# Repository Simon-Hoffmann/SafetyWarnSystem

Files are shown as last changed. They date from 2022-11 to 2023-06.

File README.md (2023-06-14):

# SafetyWarnSystem

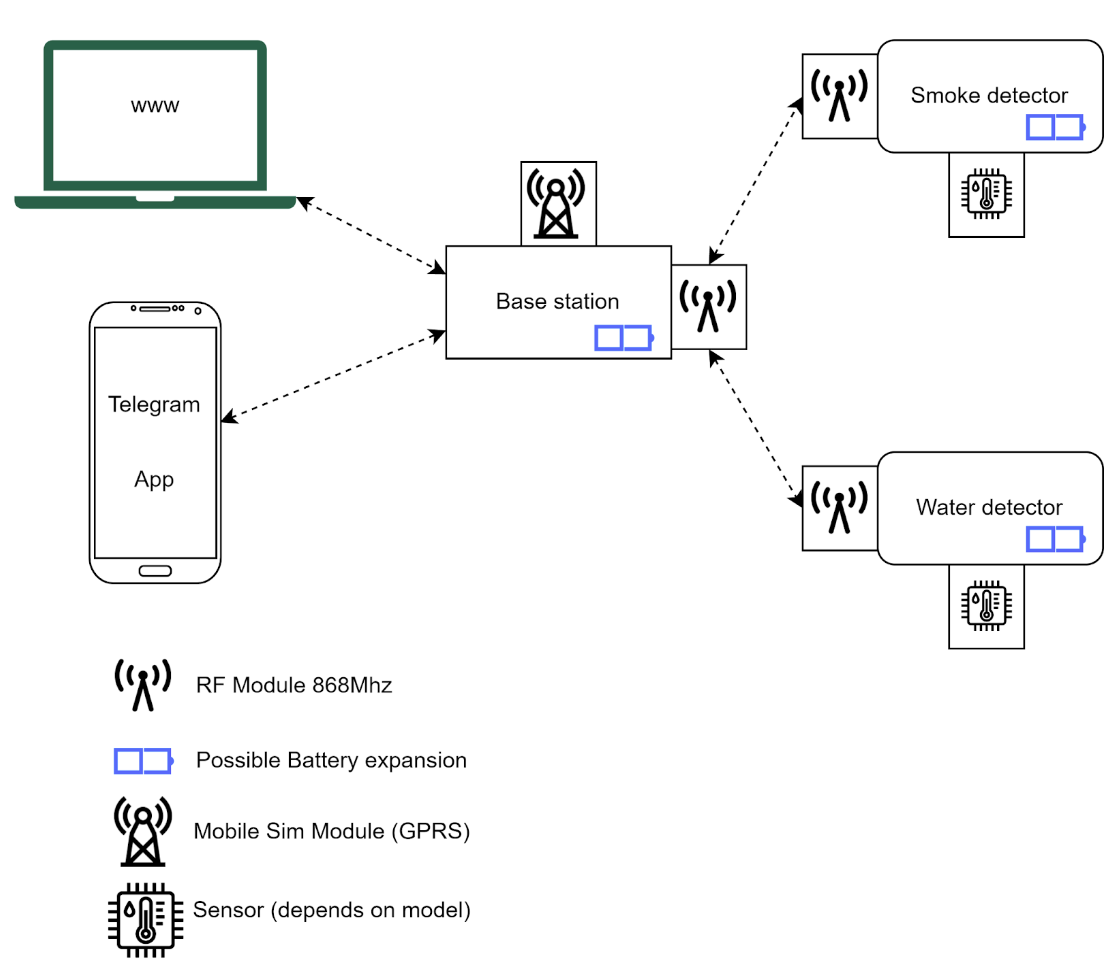
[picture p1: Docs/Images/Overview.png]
System


Introducing our Safety Warn System, a comprehensive home security solution designed to keep you and your loved ones safe at all times.

At the heart of the Safety Warn System is the Base Station, serving as the centralized hub for all sensor communication. This device is easily installed in your home, acting as the control center for your security network. Equipped with radio frequency technology, the Base Station seamlessly interacts with the array of sensors connected to it, ensuring real-time monitoring and instant notifications.

The Safety Warn System includes four essential sensors, each playing a crucial role in safeguarding your home. The Smoke and Gas Alarm sensor ensures early detection of smoke and potentially harmful gases, promptly alerting you to potential fire hazards or gas leaks. The Water Detector sensor is designed to identify any water leaks or floods, enabling you to take immediate action and prevent costly water damage. Lastly, the Door Open Detector sensor provides reliable surveillance, instantly notifying you whenever a door or window is opened, securing your home against intrusions.

When any of the sensors detect an issue, they immediately communicate with the Base Station, relaying the crucial information. The Base Station acts as the liaison, promptly relaying notifications to you through a user-friendly website and a dedicated Telegram bot. This allows you to conveniently access the Base Station from anywhere, giving you complete control and situational awareness of your home security.

Through the intuitive website and Telegram bot, you can monitor the status of each sensor, view real-time alerts, and access historical data. Additionally, you have the ability to customize your notifications based on your preferences, ensuring that you receive the right information at the right time.

## Hardware

### Microcontroller

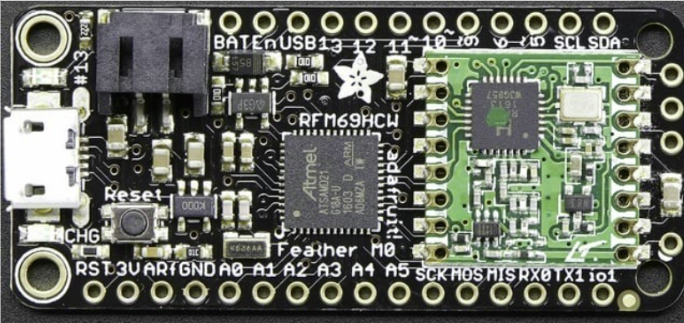
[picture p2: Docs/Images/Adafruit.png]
Controller


This adafruit board is a very useful microcontroller because of the following reasons:

- It has a built in RFM module
- It has a battery port for direct battery operation support
- Its form is very small, smaller than the 2 previous microcontrollers
- Adafruit works with the Arduino IDE and with this supports all Arduino libraries

Each microcontroller will have a button for resetting the sensor to factory settings. The following was chosen because it short circuits two connections on press, allowing the use of an interrupt to wake the sensor up during sleep. I did not compare other buttons, since there aren’t many criteria for the button, so any cheap button will do.

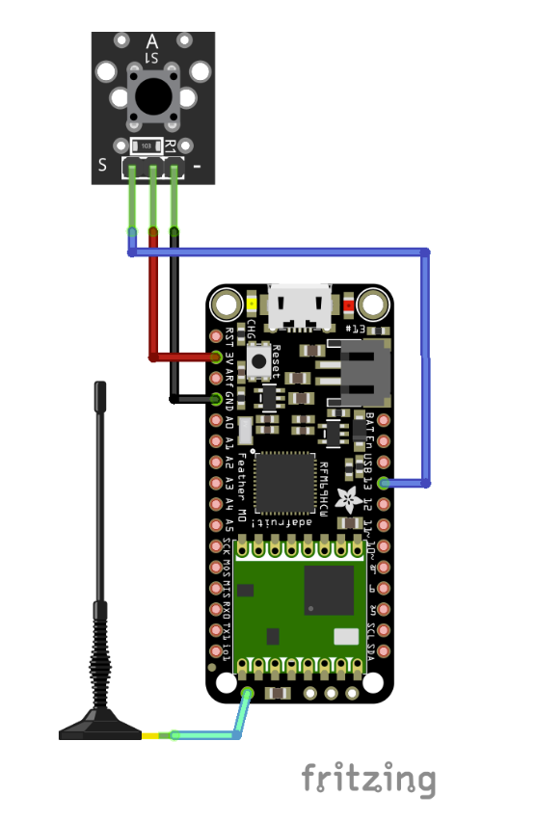
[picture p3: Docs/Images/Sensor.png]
Sensor


### Smoke Detector and Gas Detector

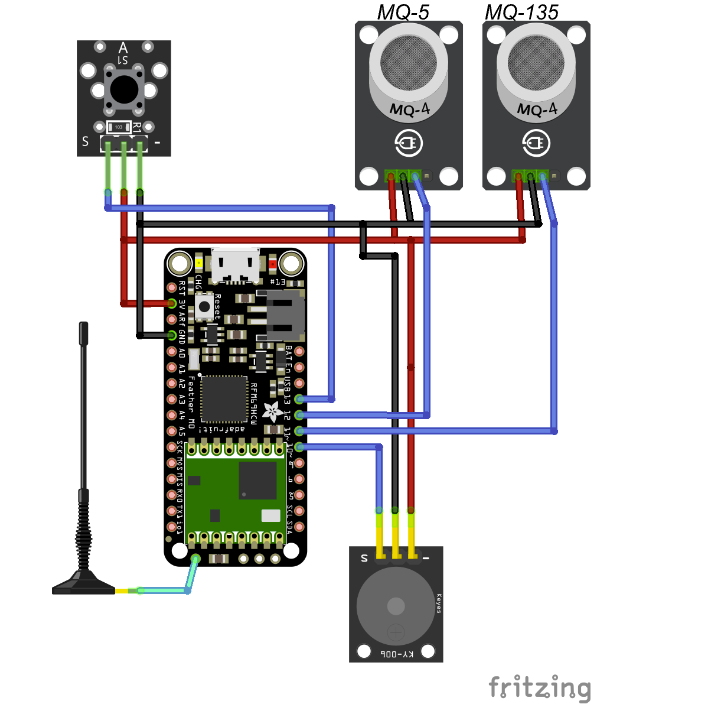
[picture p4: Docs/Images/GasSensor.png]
GasSensor


The smoke detector needs three different hardware components:
- MQ-135 Sensor has the capabilities of detecting: Benzene, alcohol, smoke in the air or to measure the air quality.
- MQ-5 Sensor has the capabilities for measuring the concentration of liquefied petroleum gases (LPG), carbon monoxide (CO), methane (CH4) and hydrogen (H2) in the air.
- A buzzer to indicate the detection of smoke or a dangerous gas with a loud beeping sound.

The smoke detector also needs to have a button with the functionality of turning off the buzzer alarm manually when it goes off. For this purpose, the button on the microcontroller of the sensor module will be used. 

### Water sensor

WaterSensor

## Door sensor

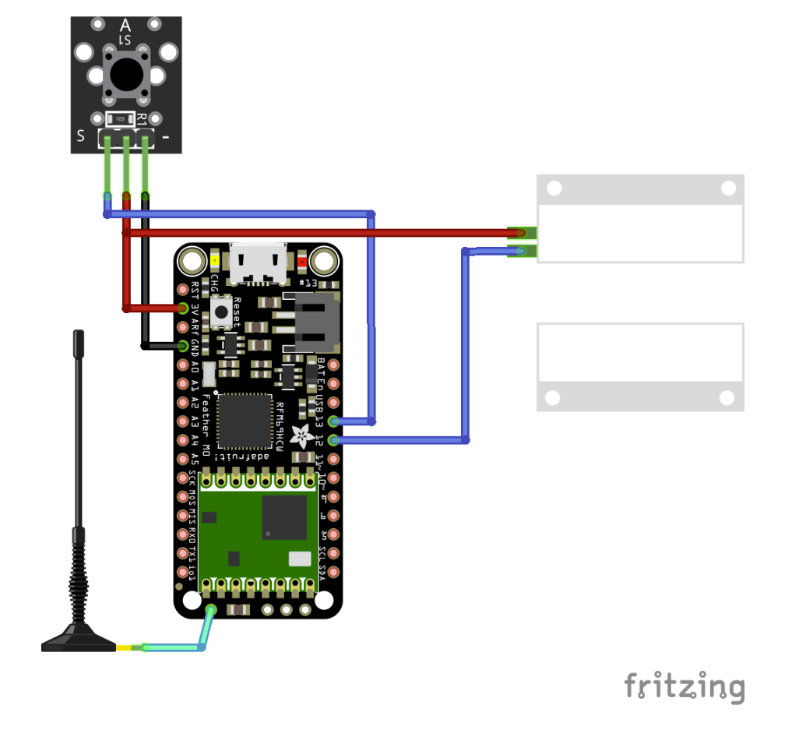
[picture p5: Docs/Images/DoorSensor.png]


## Communication

Before we could begin with the implementation of the sensors, we had to decide how the communication would be done between the sensors and the base station. We came up with the following solution.

### Packet Format

| idSensor | idBase | packetID | packetType | DataLength | Data |
| --- | --- | --- | --- | --- | --- |
| uint8_t | uint8_t | uint8_t | uint8_t | uint8_t | variable |

- idSensor    -       	unique id for sensor
- isBase      -       	unique id for Base Station
- packetID    -       	unique packet id for when a message is answered
- packetType 	-       	The type of data being sent
- DataLength 	-	        Indicates packet length
- Data        -       	Packet data

### Packet types

| Packettype | idSensor | idBase | packetID | packetType | Data |
| --- | --- | --- | --- | --- | --- |
| CONNECT | 0 | 0 | uint8_t | 1 | Sensor Type*  |
| CONNACK | 0 | 0 | uint8_t | 2 | ID for Sensor*|
| | | | | 3 | |
| ACK | uint8_t | uint8_t | uint8_t | 4 | - |
| SEND | uint8_t | uint8_t | uint8_t | 5 | See Send data |
| PING | uint8_t | uint8_t | uint8_t | 6 | - |
| DISCONNECT | uint8_t | uint8_t | uint8_t | 7 | - |

*uint8_t
Sensor Type: 
- 1 - Water sensor
- 2 - Smoke detector
- 3 - Door sensor

### Send data

Water Sensor

| Sensor type | Submerged (uint8_t)  |
| --- | --- |
| 1 | 0 or 1 |

Smoke Sensor

| Sensor type | Gas detection - time turned off (uint8_t) minutes  | Smoke sensor (uint16_t) ppm | Gas sensor (uint16_t) ppm |
| --- | --- | --- | --- |
| 2 | n | n | n |

Door Sensor

| Sensor type | Door state (uint8_t) |
| --- | --- |
| 3 | 0 open or 1 closed |

### Communication examples

#### Connection establishment new Connection

Sensor has no ID (Default: 0) meaning it needs one assigned

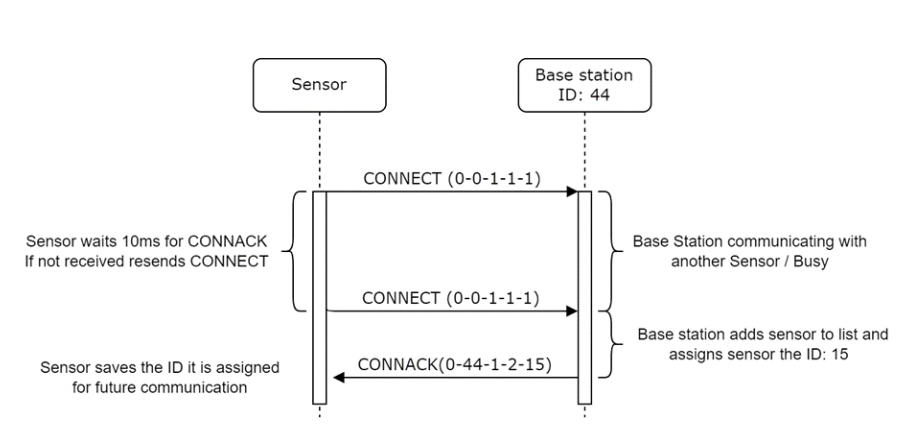
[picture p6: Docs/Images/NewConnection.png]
NewConnection


If the sensor doesn’t receive a CONNACK after 10 tries it sleeps for 1 min.

#### Connection establishment existing Connection

Sensor has ID: 15

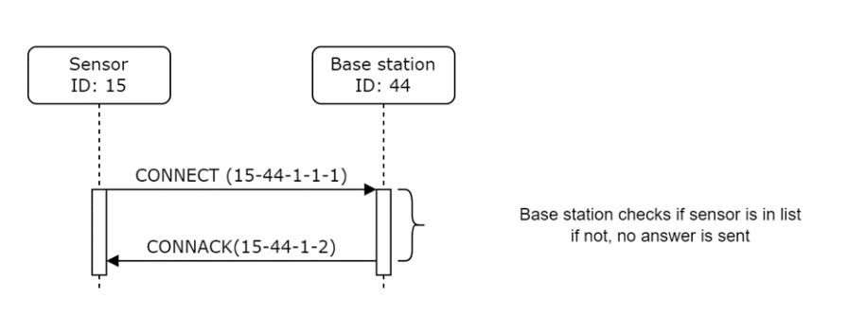
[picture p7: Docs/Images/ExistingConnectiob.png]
ExistingConnection


If the sensor doesn’t receive a CONNACK after 10 tries it sleeps for 1 min.

#### Disconnect

Disconnect can only be done upon receiving a PING Packet or SEND Packet, because the Sensor RF Module is not constantly active. The SEND happens every 10 minutes, allowing a relatively timely disconnect.
If the base does not get an ACK after 10 tries, it will retry disconnect after the next ping from the sensor.
To disconnect a sensor it should be deleted from the sensor_data.json

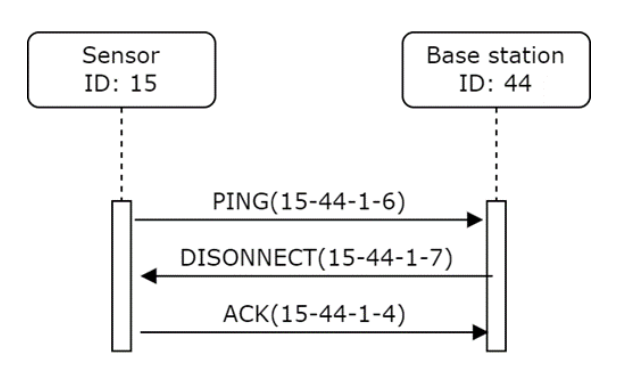
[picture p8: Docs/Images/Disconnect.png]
Disconnect


#### Ping

The sensor must send a PING Packet ever 1min to the Base station to indicate it is still active. If the base station does not receive a packet after 10min, it sets the sensor status to offline/error.
If the sensor does not get an ACK/DISCONNECT after 10 tries, it must retry connecting to the station.

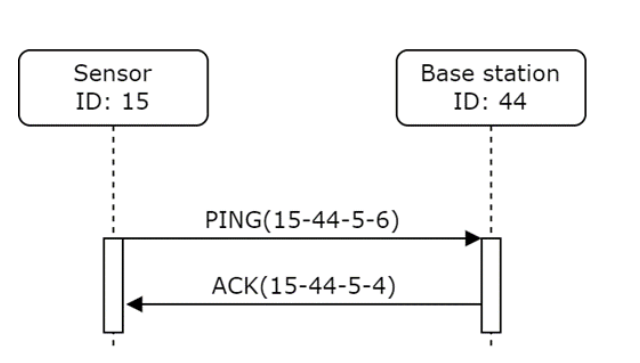
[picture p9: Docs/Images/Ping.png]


#### Sending Data

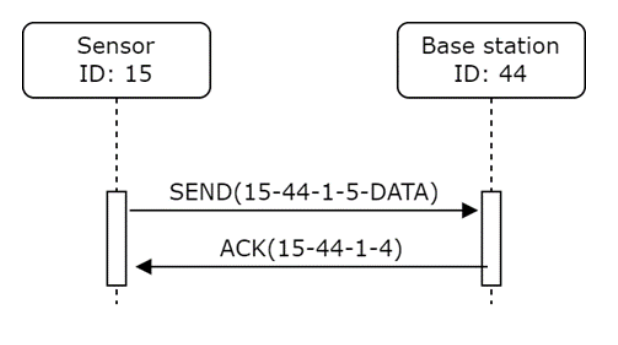
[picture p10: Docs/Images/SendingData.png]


Data is sent until an acknowledge is received (every 10ms up to 10 tries)
Base station sends ACK back to the sensor.
If the sensor does not get an ACK/DISCONNECT after 10 tries, it must retry connecting to the station.
Base station ignores duplicate messages.
If the base station does not receive a packet after 15min, it sets the sensor status to offline/error.

## Program flow chart

This flowchart is only for a rough overview and does not go into every specific detail. It is for a rough idea of how the sensors should operate.

### Program start

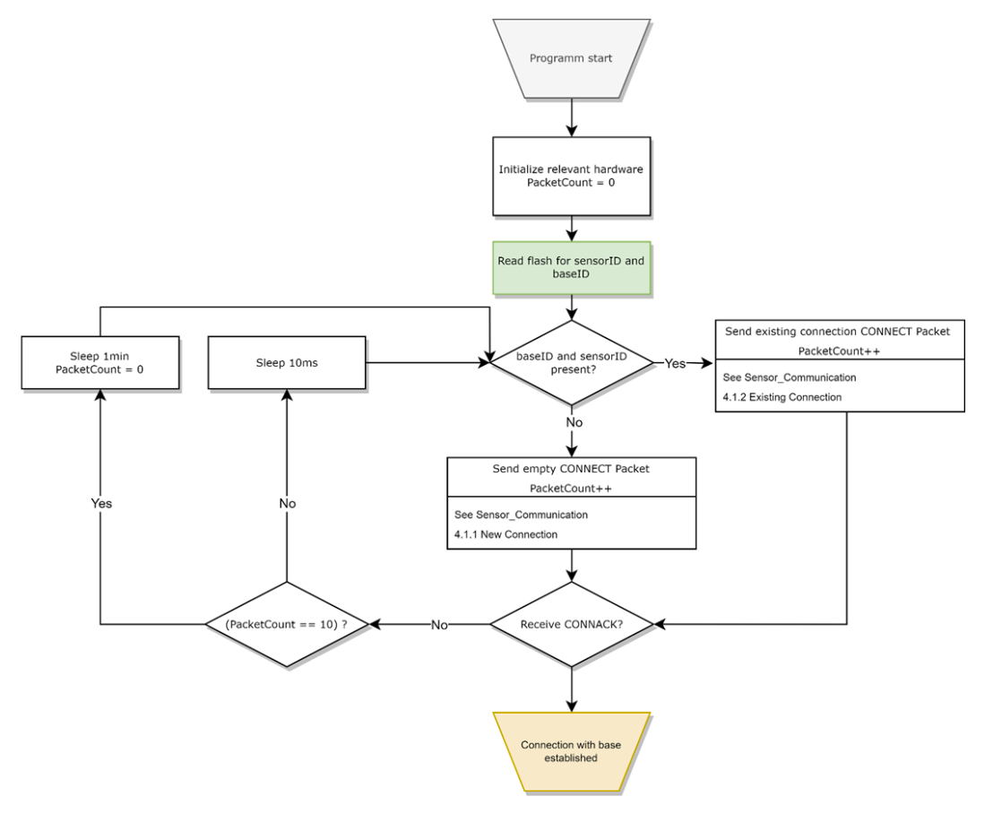
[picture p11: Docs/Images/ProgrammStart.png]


### Connected with base station

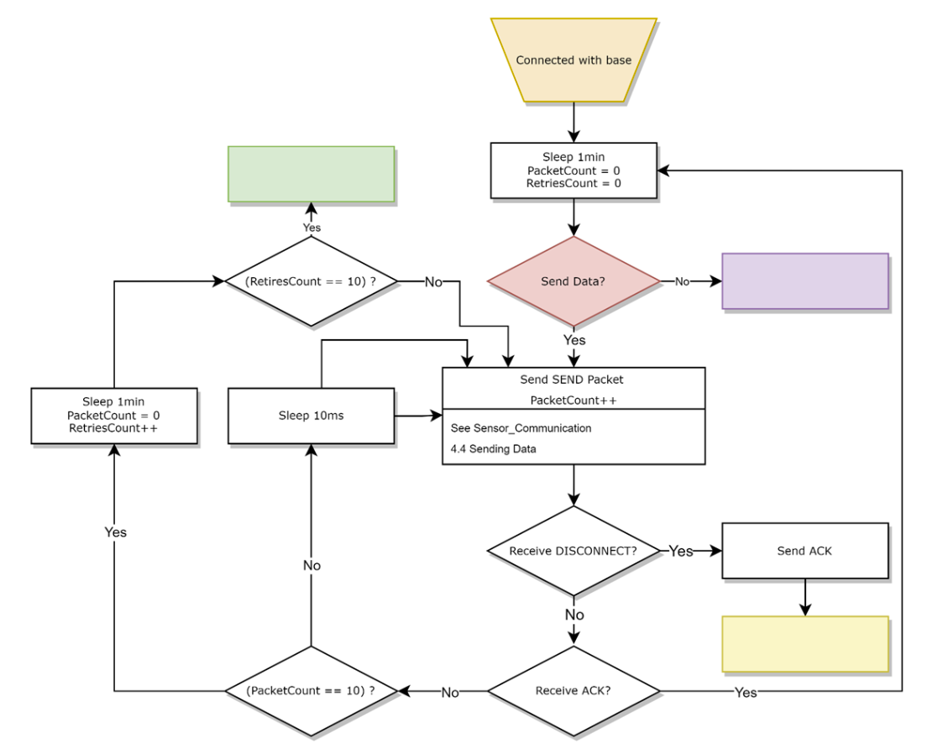
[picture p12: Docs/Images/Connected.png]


### Ping

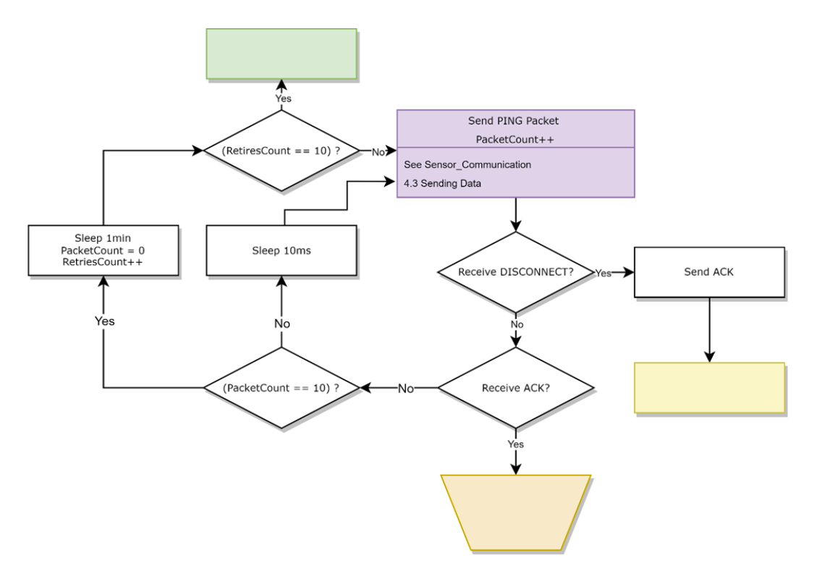
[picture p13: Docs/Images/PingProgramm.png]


### Sensor warning interrupt

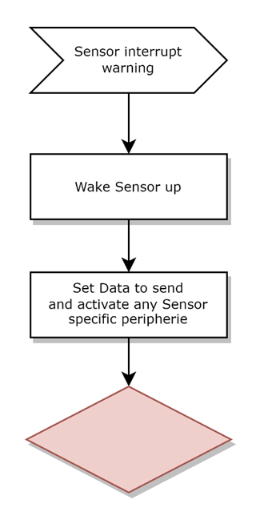
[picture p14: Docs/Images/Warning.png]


### Reset button main sensor

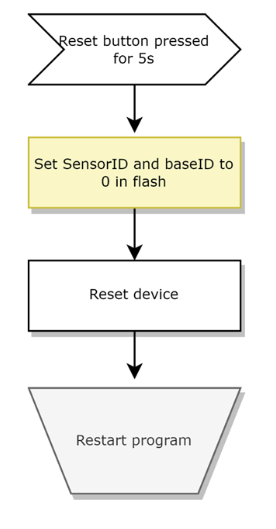
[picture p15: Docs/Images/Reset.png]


### Reset button smoke sensor

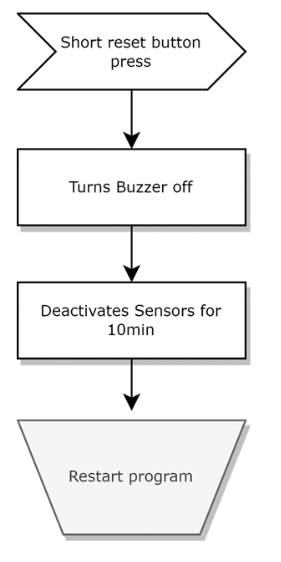
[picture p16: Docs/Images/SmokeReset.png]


### Reset button main sensor

Disconnect

## TODO

The base station and website are projects from other students in my course, which are currently not in this repository

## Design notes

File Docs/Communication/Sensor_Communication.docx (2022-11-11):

# Client-Server Communication Model

# Between sensor and base station

Author: Simon Hoffmann

Last edited: 09.11.2022

# 1. Packet format

idSensor | idBase | packetID | packetType | Data | End identifier
uint8_t | uint8_t | uint8_t | uint8_t | variable | ~

idSensor - unique id for sensor

isBase - unique id for Base Station

packetID - unique packet id for when a message is answered

packetType - The type of data being sent

Data - Packet data

End identifier - Indicates end of package

# 2. Packet types

Packettype | idSensor | idBase | packetID | packetType | Data
CONNECT | 0 | 0 | n | 1 | Sensor Type*
CONNACK | 0 | uint8_t | n | 2 | Id for Sensor+
| | | | 3
ACK | uint8_t | uint8_t | m | 4 | -
SEND | uint8_t | uint8_t | k | 5 | See Send Data
PING | uint8_t | uint8_t | i | 6 | -
DISCONNECT | uint8_t | uint8_t | g | 7 | -

+Id for Sensor (uint8_t)

*Sensor Type (uint8_t):

1 – Water sensor

2 – Smoke detector

3 –

# 3. Send Data

First part is uint8_t with type of sensor

## 3.1 Water Sensor

The Raspberry pi Pico have temperature sensors, the conversion must be done base station side.

Sensor type (uint8_t) | Humidity (uint16_t) | Submerged (uint8_t) | Temperature (uint16_t)
1 | n | 0 or 1 | n

## 3.2 Smoke Detector

Sensor type (uint8_t) | Smoke / CO2 detection | CO detection | Temperature (uint16_t)
2 | Not sure if can discern the difference | Not sure if can discern the difference | n

# 4. Communication examples

## 4.1 Connection establishment

### 4.1.1 New Connection

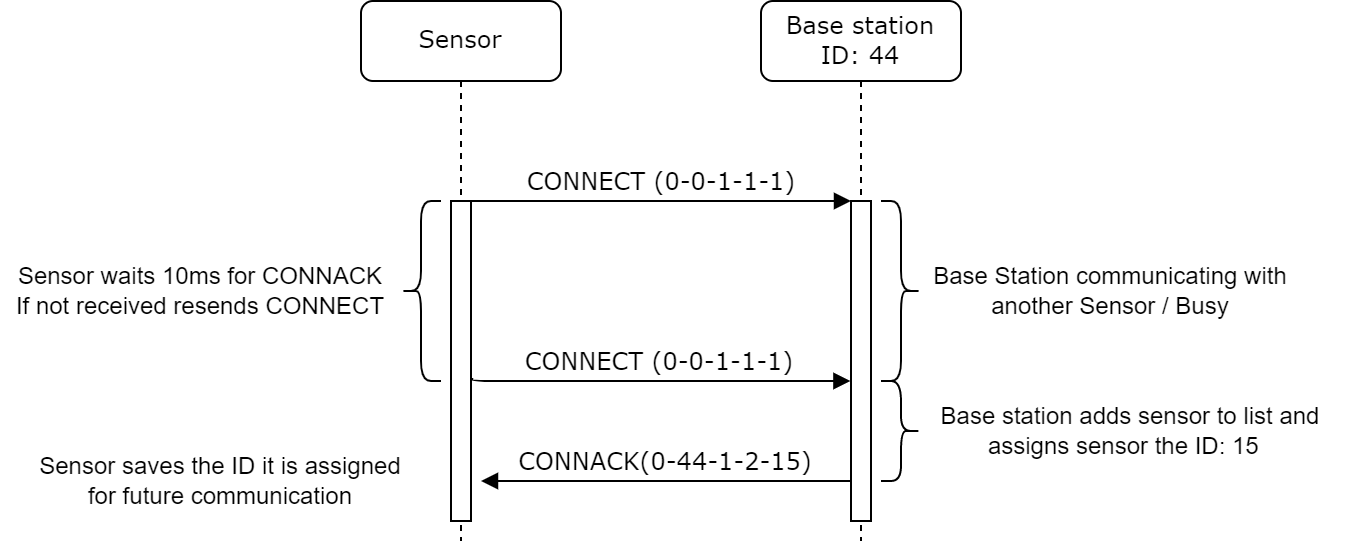
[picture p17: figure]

Sensor has no ID (Default: 0) meaning it needs one assigned

If sensor doesn’t receive a CONNACK after 10 tries it sleeps for 1min.

### 4.1.2 Existing Connection

Sensor has ID: 15

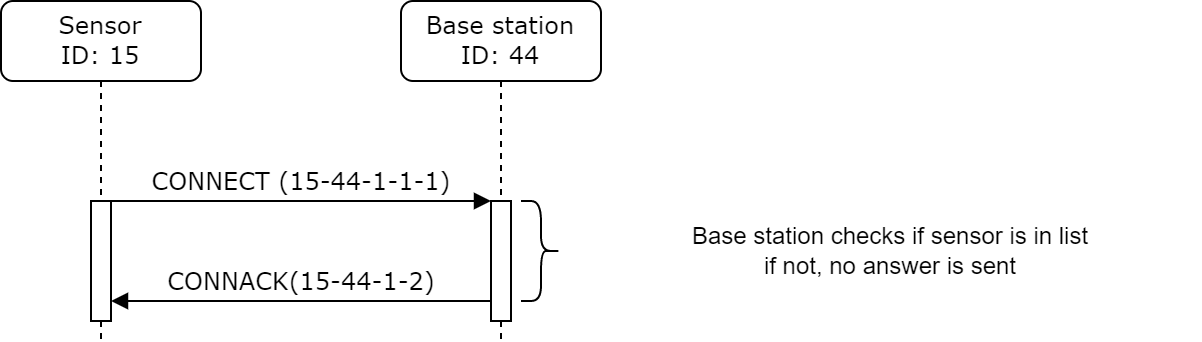
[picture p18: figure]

If sensor doesn’t receive a CONNACK after 10 tries it sleeps for 1min.

## 4.2 Disconnect

Disconnect can only be done upon receiving a PING Packet, because the Sensor RF Module is not constantly active. The Ping happens every minute, allowing a relatively timely disconnect.

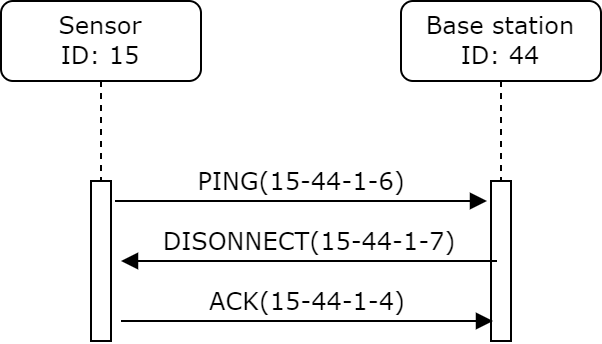
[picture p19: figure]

## 4.3 Connection available (PING)

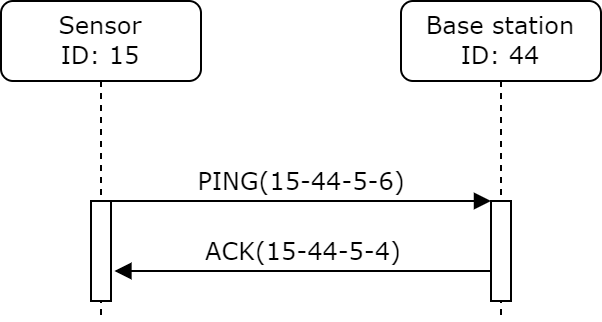
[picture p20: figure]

The sensor must send a PING Packet ever 1min to the Base station to indicate it is still active. If the base station does not receive a packet after 2min, it sets the sensor status to offline/error.

If the sensor does not get an ACK/DISCONNECT after 10 tries, it must retry connecting to the station.

This must only happen if nothing was sent in the 1min span.

## 4.4 Sending Data

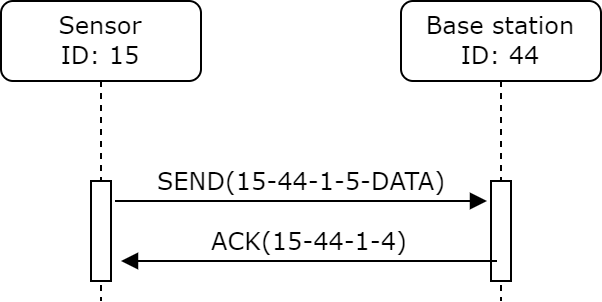
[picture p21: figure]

Data is sent until an acknowledge is received (every 10ms up to 10 tries)

Base station sends ACK back to sensor.

If the sensor does not get an ACK/DISCONNECT after 10 tries, it must retry connecting to the station.

Base station must ignore duplicate messages (with previous and current states maybe)

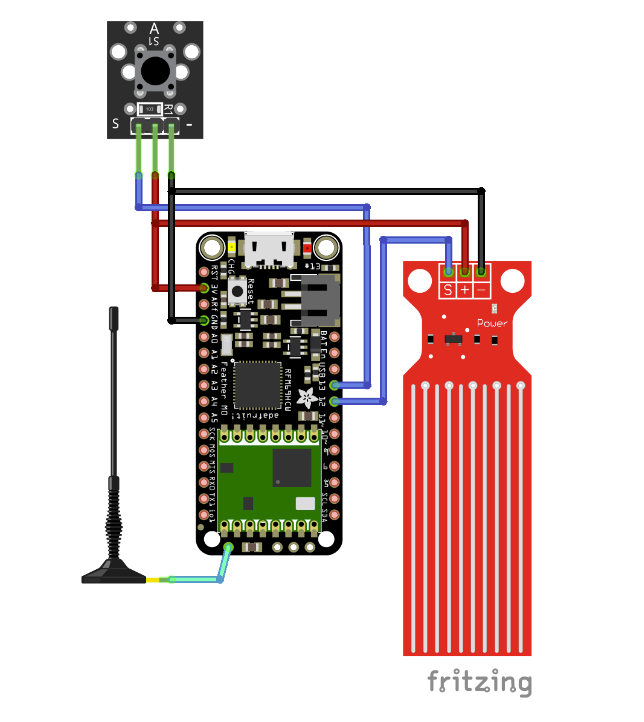
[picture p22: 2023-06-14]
Docs/Images/WaterSensor.png

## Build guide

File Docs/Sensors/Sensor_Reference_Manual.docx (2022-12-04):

Sensor Reference Manual

Author: Simon Hoffmann

Last edited: 3.12.2022

# 1. Program Flow-Chart

This flowchart is only for a rough overview and does not go into every specific detail.

## 1.1 Program start

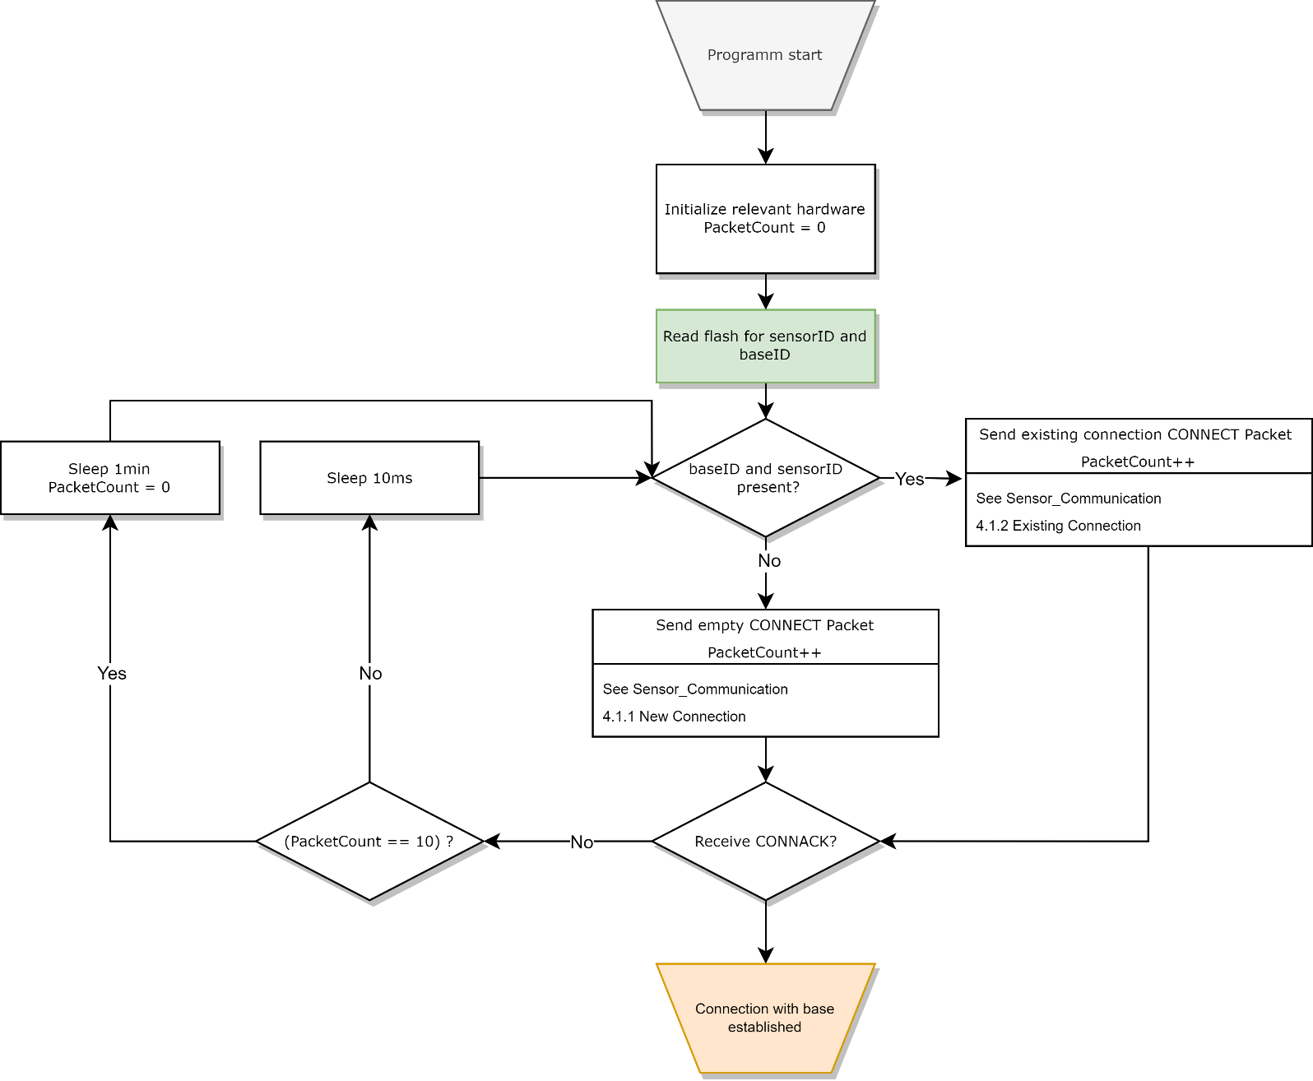
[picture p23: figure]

The program start initialises all hardware and tries to establish a connection with a base station.

See Connection with base established.

## 1.2 Connected with base station

The Sensor goes into sleep mode to save battery, when awoken it checks if it needs to send data, otherwise it sends a ping to let the base station know it is still active.

This is dependent on the sensor, some send constant information like temperature, others only if an event has occurred.

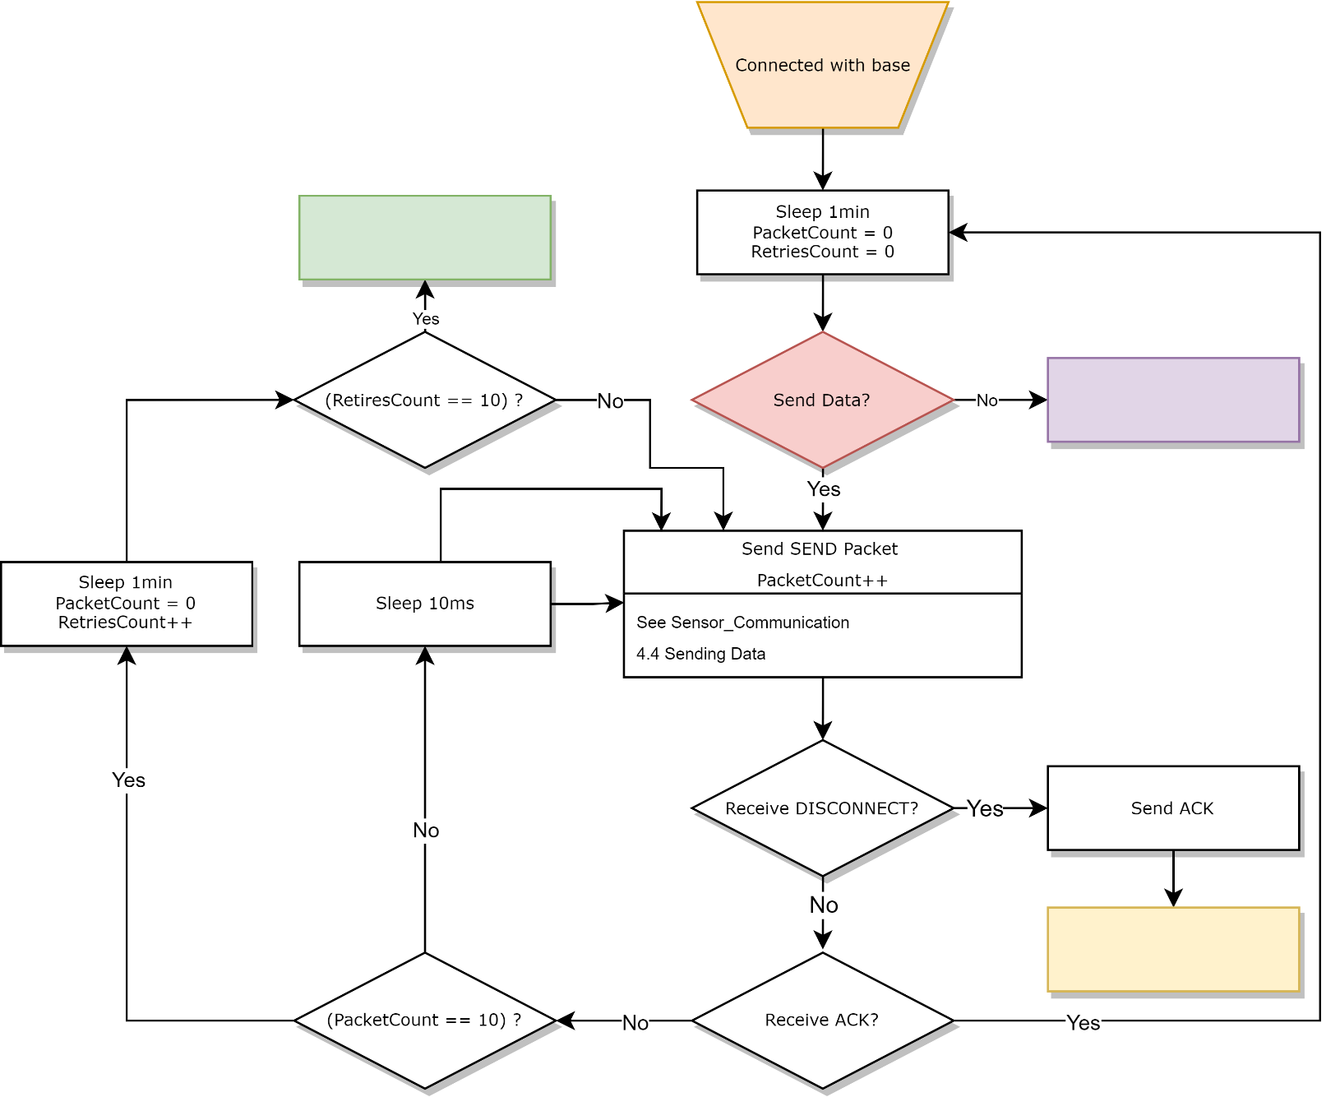
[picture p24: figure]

If an event has occurred that data precedes any other data trying to be sent.

See (RetriesCount == 10) ,No Data to send.

## 1.3 PING

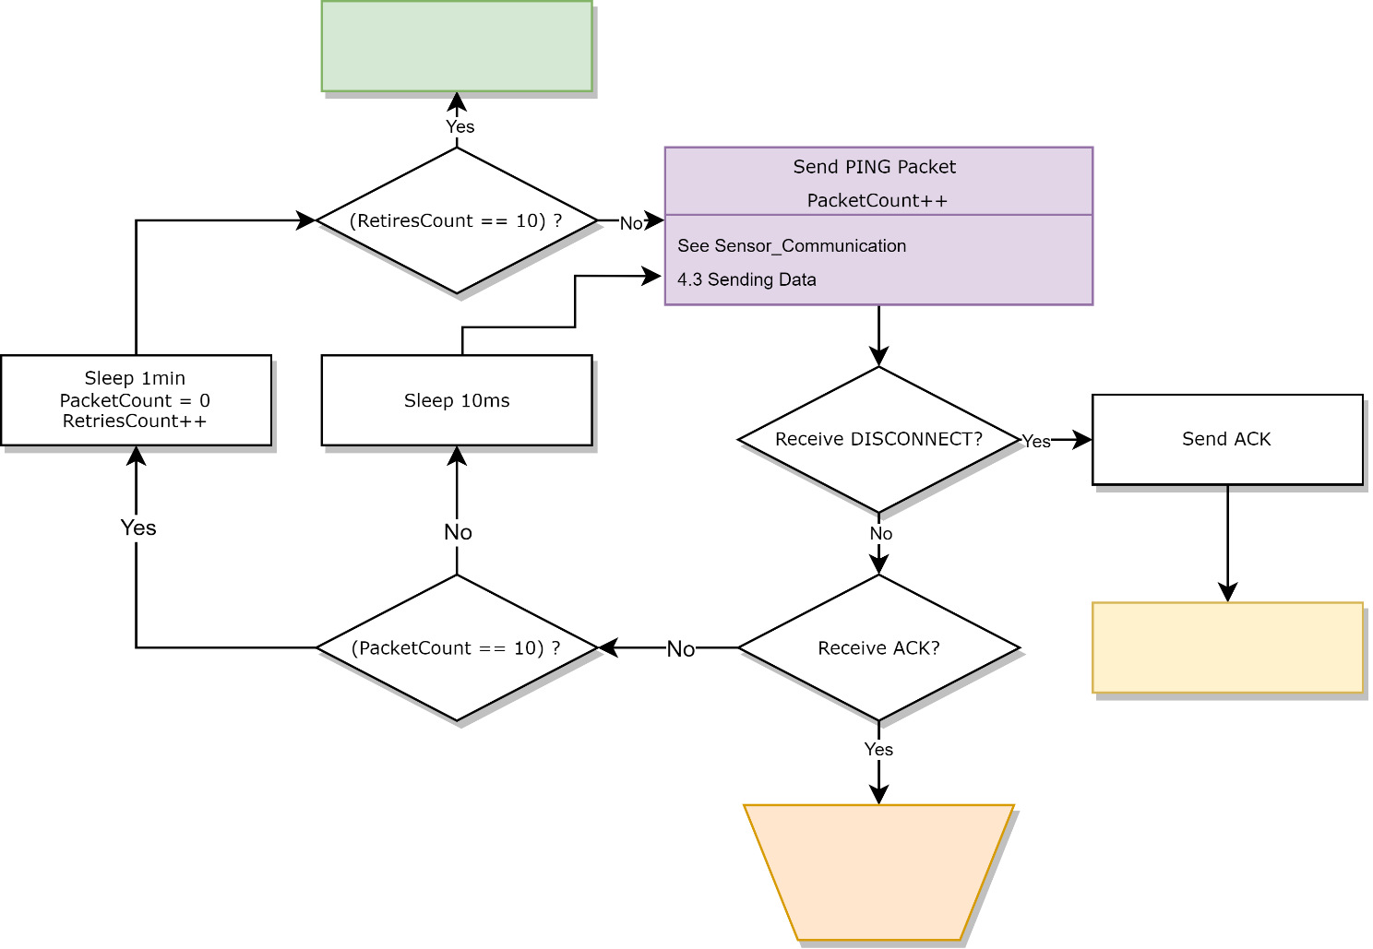
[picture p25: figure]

See (RetiresCount == 10), Send ACK, Received ACK.

## 1.4 Sensor warning interrupt

This is executed in an interrupt context, the exact implementation is Sensor dependent.

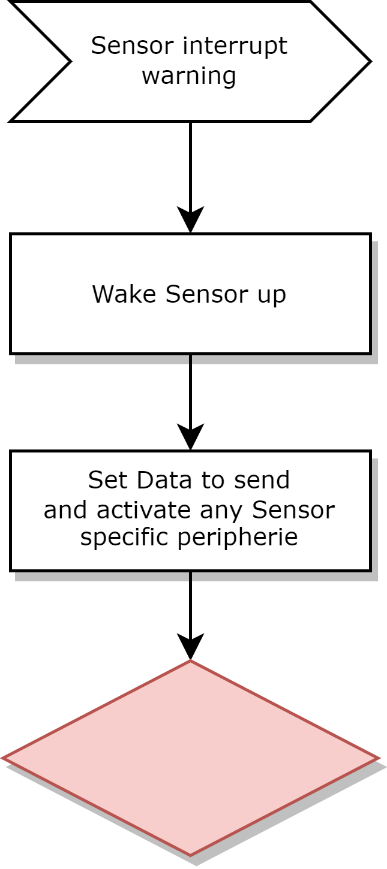
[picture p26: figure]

See Send Data.

## 1.5 Reset button held for 5s

This allows a user to manually reset the Sensor to connect it to a different base station.

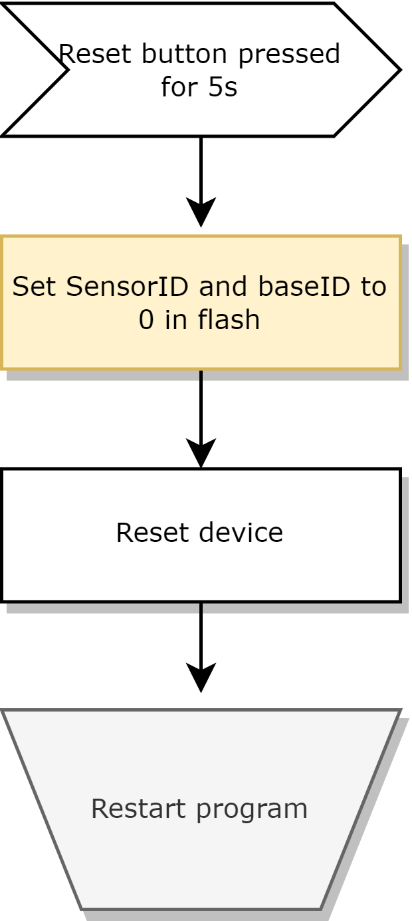
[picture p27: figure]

See Start Program.

## 1.6 Sensor Specific: Smoke detector – Reset button pressed shortly

This functionality is only on the Smoke detector sensor

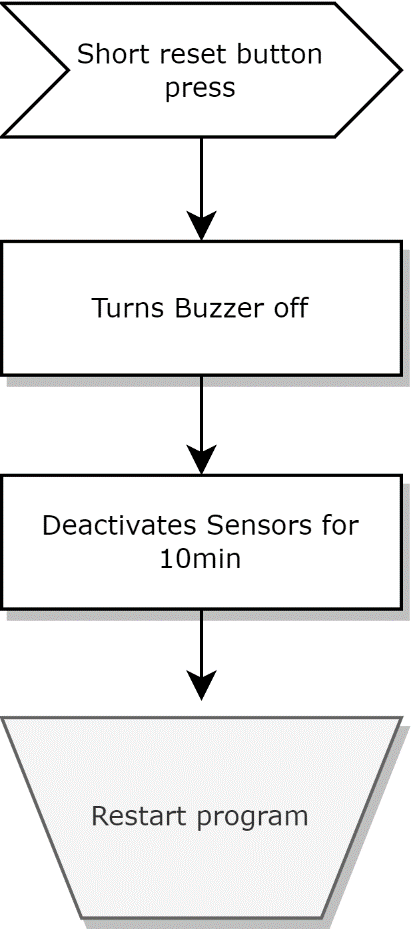
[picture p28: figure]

See Program start.

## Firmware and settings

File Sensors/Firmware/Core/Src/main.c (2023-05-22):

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
/* Includes ------------------------------------------------------------------*/
#include "main.h"
#include "rfm69w.h"
#include <string.h>

SPI_HandleTypeDef hspi2;

TIM_HandleTypeDef htim1;

void SystemClock_Config(void);
static void MX_GPIO_Init(void);
static void MX_SPI2_Init(void);
static void MX_TIM1_Init(void);
#define Send 0
#define Receive 1

/**
  * @brief  The application entry point.
  * @retval int
  */
int main(void)
{
  /* MCU Configuration--------------------------------------------------------*/

  /* Reset of all peripherals, Initializes the Flash interface and the Systick. */
  HAL_Init();

  /* Configure the system clock */
  SystemClock_Config();

  /* Initialize all configured peripherals */
  MX_GPIO_Init();
  MX_SPI2_Init();
  MX_TIM1_Init();
  /* USER CODE BEGIN 2 */
  	SWS_Packet packet;
    DataBuffer buffer;
    SmokeSensorData smokeData;
    packet.packetID = 0;
    packet.idBase = 1;
    packet.idSensor = 2;
    packet.packetID = packet.packetID + 1;
    packet.packetType = SEND;
//    smokeData.GasDetectionTimeout_Minutes = 10;
//    smokeData.GasSensor = 500;
//    smokeData.SmokeSensor = 1000;
//    smokeData.SensorType = 2;
//    smokeData.Temperature = 52;

#if Send
    memcpy(packet.data, &smokeData, 8);

    packet_serializeData(&packet, &buffer);
#endif

  /* USER CODE END 2 */

  /* Infinite loop */
  /* USER CODE BEGIN WHILE */
  bool RFM_active = false;
#if Send
  RFM_active = RFM69_initialize(RF69_868MHZ, 1, 0);

  while(!RFM_active){
	  RFM_active = RFM69_initialize(RF69_868MHZ, 1, 0);
	  HAL_Delay(1000);
  }
#endif
#if Receive
  RFM_active = RFM69_initialize(RF69_868MHZ, 2, 1);

  while(!RFM_active){
	  RFM_active = RFM69_initialize(RF69_868MHZ, 2, 1);
	  HAL_Delay(1000);
  }
#endif

#if Receive
  RFM69_setMode(RF69_MODE_RX);
#endif
  while (1)
  {
    /* USER CODE END WHILE */
	  if(RFM_active){
#if Send
		  RFM69_setMode(RF69_MODE_RX);
		  if(RFM69_canSend()){
			  RFM69_setMode(RF69_MODE_TX);
			  RFM69_send(RF69_BROADCAST_ADDR, buffer.data, buffer.size, false);
			  HAL_GPIO_WritePin(GPIOA, GPIO_PIN_5, 1);
		  }
		  RFM69_setMode(RF69_MODE_RX);
		  HAL_Delay(2500);
		  HAL_GPIO_WritePin(GPIOA, GPIO_PIN_5, GPIO_PIN_RESET);
		  HAL_Delay(2500);
#endif

#if Receive
		  if(RFM69_receive(buffer.data, buffer.size)){
			  packet_deserializeData(&packet, &buffer);
			  memcpy(&smokeData, packet.data, 8);
		  }
		  HAL_Delay(500);
#endif
	  }
    /* USER CODE BEGIN 3 */
  }
  /* USER CODE END 3 */
}

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


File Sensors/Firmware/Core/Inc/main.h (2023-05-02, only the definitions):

#define B1_Pin GPIO_PIN_13
#define B1_GPIO_Port GPIOC
#define USART_TX_Pin GPIO_PIN_2
#define USART_TX_GPIO_Port GPIOA
#define USART_RX_Pin GPIO_PIN_3
#define USART_RX_GPIO_Port GPIOA
#define LD2_Pin GPIO_PIN_5
#define LD2_GPIO_Port GPIOA
#define SPI_SCK_Pin GPIO_PIN_13
#define SPI_SCK_GPIO_Port GPIOB
#define SPI_MISO_Pin GPIO_PIN_14
#define SPI_MISO_GPIO_Port GPIOB
#define SPI_MOSI_Pin GPIO_PIN_15
#define SPI_MOSI_GPIO_Port GPIOB
#define SPI_DI0_Pin GPIO_PIN_6
#define SPI_DI0_GPIO_Port GPIOC
#define SPI_CS_Pin GPIO_PIN_7
#define SPI_CS_GPIO_Port GPIOC
#define CUSTOMNAME_Pin GPIO_PIN_9
#define CUSTOMNAME_GPIO_Port GPIOC
#define Sensor0_Pin GPIO_PIN_9
#define Sensor0_GPIO_Port GPIOA
#define Sensor1_Pin GPIO_PIN_10
#define Sensor1_GPIO_Port GPIOA
#define Sensor2_Pin GPIO_PIN_11
#define Sensor2_GPIO_Port GPIOA
#define Sensor3_Pin GPIO_PIN_12
#define Sensor3_GPIO_Port GPIOA
#define TMS_Pin GPIO_PIN_13
#define TMS_GPIO_Port GPIOA
#define TCK_Pin GPIO_PIN_14
#define TCK_GPIO_Port GPIOA
#define SWO_Pin GPIO_PIN_3
#define SWO_GPIO_Port GPIOB

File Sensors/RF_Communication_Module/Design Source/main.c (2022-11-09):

// ========================================================
/// @file       main.c
/// @brief      Main function of the RFDK_PIC16_LCD_ver1.1
/// @version    V2.1
/// @date       2013/12/25
/// @company    HOPE MICROELECTRONICS Co., Ltd.
/// @website    http://www.hoperf.com
/// @author     Geman Deng
/// @mobile     +86-013244720618
/// @tel        0755-82973805 Ext:846
// ========================================================
#include "DK_PIC16_App.h"

u16 gw_TimerCount=0;

void InitPort(void);
void InitSfr(void);
void timer1_init(void);
void timer2_init(void);
void Uart_init(void);
void interrupt ISR_timer(void);
void PowerUpDelay(void);
void PowerOnMusic(void);  


__CONFIG(0x3FFF29E4);
void main(void)
{
  u8 TxFlag=0;
  u8 RxFlag=0;

  InitSfr();                                               //PIC16 Register Initialization
  PowerUpDelay();                                          //Power on delay  
  InitPort();                                              //PIC16 IO port Initialization
  timer1_init();
  timer2_init();
  LCD_Init();                                              //LCD initialize
  BeepOff();                                               //Close buzzer
  ModuleSelectModeEntryCheck();                            //Confirm whether you can enter module select mode
  Uart_init();
  PowerOnMusic();                                          //Power on music
  
  while(1)
  { 
    MenuConfig();                                          //Menu config & display
    if(gb_ModuleWorkEnableFlag)
    {
      RFM66_Running(gb_SystemMode,gb_ModuleWorkMode,gb_ParameterChangeFlag,&TxFlag,&RxFlag,&gb_RF_RSSI);
        
      if(TxFlag==1)                                        //Sent successfully
      {
        TxFlag=0; 
        gw_SendDataCount++;
        if(gw_SendDataCount>9999){gw_SendDataCount=0;}
      }
      if(RxFlag==1)                                        //Successfully received
      {
        RxFlag=0; 
        gw_ReceiveDataCount++;
        if(gw_ReceiveDataCount>9999){gw_ReceiveDataCount=0;}
      }
          
            
      if(gb_ParameterChangeFlag==1){gb_ParameterChangeFlag=0;}    //clear parameter flag
      if(gb_ModuleWorkMode!=C_ModuleWorkMode_FSK && gb_ModuleWorkMode!=C_ModuleWorkMode_OOK && gb_ModuleWorkMode!=C_ModuleWorkMode_LoRa)
      {
        gb_StatusTx=0;
        gb_StatusRx=0;
      }
    }
    else
    {
      gb_StatusTx=0;
      gb_StatusRx=0;
    }
    if(gb_ErrorFlag!=1)
    {  
      TxLED_Deal();                                        //Tx LED display deal
      RxLED_Deal();                                        //Rx LED display deal 
    }
  }
}

/**********************************************************
**Name:     InitPort
**Function: Initialize Port
**Input:    none
**Output:   none
**********************************************************/
void InitPort(void)
{ 
  PORTA = PIC16_PORTA;
  LATA = PIC16_LATA;
  TRISA = PIC16_TRISA;
  ANSELA= PIC16_ANSELA;
  
  PORTB = PIC16_PORTB;
  LATB = PIC16_LATB;
  TRISB = PIC16_TRISB;
  WPUB = PIC16_WPUB;
  ANSELB= PIC16_ANSELB;
  
  PORTC = PIC16_PORTC;
  LATC = PIC16_LATC;
  TRISC = PIC16_TRISC;
  ANSELC= PIC16_ANSELC;
  
  PORTD = PIC16_PORTD;
  LATD = PIC16_LATD;
  TRISD = PIC16_TRISD;
  ANSELD= PIC16_ANSELD;
  
  PORTE = PIC16_PORTE;
  LATE = PIC16_LATE;
  TRISE = PIC16_TRISE;
  WPUE = PIC16_WPUE;
  ANSELE= PIC16_ANSELE;
}

/**********************************************************
**Name:     InitSfr
**Function: Register Initialization
**Input:    none
**Output:   none
**********************************************************/
void InitSfr(void)
{
  OSCCON = 0x78;                                           //Internal crystal(16M)
  OPTION_REG = 0x06;
  WDTCON = 0x02;                                           //Close WDT, DivideRatio=1:128
  PCON = 0x00;            

  FVRCON = 0;                                              //Clear FVRCON     
  APFCON = 0;                                              //Clear APFRCON 
  BORCON = 0;                                              //Clear BORCON     
  ANSELA = 0;                                              //Clear PORTA AD channel
  ANSELB = 0;                                              //Clear PORTB AD channel
  ANSELC = 0;                                              //Clear PORTC AD channel
  ANSELD = 0;                                              //Clear PORTD AD channel
  ANSELE = 0;                                              //Clear PORTE AD channel

  INTCON = 0;                                              //Clear Interrupt
  PIR1 = 0;
  PIR2 = 0;
  ADCON0 = 0;
  
  di();                                                    //Display all interrupt
}

/**********************************************************
**Name:     timer1_init
**Function: timer1 Initialization
**Input:    none
**Output:   none
**********************************************************/
void timer1_init(void)
{
  INTCON = 0xc0;                                           //Enable interrupt
  T1CON = 0x4d;                                            //
  
  TMR1H = 0x00;                                            //Clear reload value
  TMR1L = 0x00;
  TMR1ON = 0;                                              //Close timer1
  TMR1IE = 1;                                              //Enable timer1 interrupt 
}

/**********************************************************
**Name:     timer2_init
**Function: timer2 Initialization
**Input:    none
**Output:   none
**********************************************************/
void timer2_init(void)
{
  INTCON  = 0xc0;                                          //Enable interrupt
  T2CON = 0x1d;                                            //Timer2 on, Prescaler:1:4, Postscale1:4
  PR2 = 250;                                               //1ms=16m/4 /4/4/1000(1KHZ)
  TMR2IE = 1;                                              //Enable timer1 interrupt 
}

/**********************************************************
**Name:     Uart_init
**Function: Uart Initialization
**Input:    none
**Output:   none
**********************************************************/
void Uart_init(void)
{
  TRISC7 = 1;
  TRISC6 = 1;
  SPBRGL = 0x19;     //16M crystal
  //SPBRGL = 0x20;   //20M crystal
  SPBRGH = 0x00;
  BAUDCON = 0x00;
  RCSTA = RCSTA|0x90;
  TXSTA = TXSTA|0x20;
  RCIE = 1;
  INTCON = 0xC0;
  TXIE=0; 
}
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

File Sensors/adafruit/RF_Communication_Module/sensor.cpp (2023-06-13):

/**
*	@file 	sensor.cpp
*	@author Simon Hoffmann
*	@brief	sensor implementation
*
* Contains all standard functionalities between all sensors
*/

/*-------------------------- I N C L U D E S ----------------------------*/

#include <stdint.h>
#include <Arduino.h>
#include "sensor.h"
#include "led.h"
#include "gas_sensor.h"
#include "water_sensor.h"
#include "debug.h"
#include "door_sensor.h"
#include "rfm.h"
#include "packet.h"

/* ----------- V A R I A B L E S   &  C O N S T A N T S  --------------- */

const uint8_t BUTTON_PRESS_PIN = 13;
volatile uint8_t sensorID = 0;
volatile uint8_t baseID = 0;
const int Reset = 14;
																														
/* ------------- F u n c t i o n  P r o t o t y p e s  ----------------- */

void sensor_led_startup_indication(void);
void sensor_reset(void);
void sensor_button_pressed(void);
void sensor_connectBase(void);

/* ----------------------- F U N C T I O N S  -------------------------- */

/**
*	Initialises all hardware for the sensors
*
* @details Depending on the defined sensor, the relevant hardware is initialised
*	@param 	none
*	@return none
*/
void sensor_init(void){
  //Initialize Button Interrupt
  pinMode(BUTTON_PRESS_PIN, INPUT_PULLUP);

  #ifdef GAS_SENSOR
    gas_sensor_init();
  #endif

  #ifdef WATER_SENSOR
    water_sensor_init();
  #endif

  #ifdef DOOR_SENSOR
    door_sensor_init();
  #endif

  //Initialise LED
  led_init();

  #ifdef DEBUG
  Serial.println("");
  Serial.println("Sensor initialization success");
  #endif

  #ifndef HARDWARE_DEBUG
  sensor_connectBase();
  #endif
}

/**
*	Handles initial connection with base station
*
* @details Retires every minute to connect to a base station
*	@param 	none
*	@return none
*/
void sensor_connectBase(void){
  struct swsPacket packet;
  packet.idSensor = 0;
  packet.idBase = 0;
  packet.packetType = CONNECT;
  #ifdef GAS_SENSOR
  packet.data[0] = 2;
  #endif
  #ifdef WATER_SENSOR
  packet.data[0] = 1;
  #endif
  #ifdef DOOR_SENSOR
  packet.data[0] = 3;
  #endif
  bool connected = false;

  while(!connected){
    if(rfm_send(&packet)){
      connected = true;
      sensorID = packet.data[0];
      baseID = packet.idBase;
    }else{
      #ifdef DEBUG
        Serial.println("Connection to base station could not be established, trying again in 1min");
      #endif
      #ifdef GAS_SENSOR
      //The gas sensor should still be able to have its normal function of detection even when not connected with the base station
      int timer = 0;
      while(timer < 6000){
          gas_sensor_check_no_connection();
          sensor_button_pressed();
          delay(10);
          timer++;
      }
      
      #else
      int timer = 0;
      while(timer < 6000){
          sensor_button_pressed();
          delay(10);
          timer++;
      }
      #endif
    }
  }
  #ifdef DEBUG
    Serial.println("Successful connection to Base station");
  #endif
}

/**
*	Main sensor loop
*	
*	@param 	none
*	@return none
*/
void sensor_task(void){
  static uint32_t lastDataSent_s = 0;
  static uint32_t sendTimeout = 0;

  /*---- Check sensor values for warnings ----*/


  #ifdef GAS_SENSOR
  if(gas_sensor_check()){
    lastDataSent_s = 0;
    sendTimeout = 50000;
  }
  #endif

  #ifdef WATER_SENSOR
  if(water_sensor_check()){
    lastDataSent_s = 0;
    sendTimeout = 50000;
  }
  #endif

  #ifdef DOOR_SENSOR
  if(door_sensor_check()){
    lastDataSent_s = 0;
    sendTimeout = 50000;
  }
  #endif

  /*---- Button press check ----*/
  while(sendTimeout > 0){
    sensor_button_pressed();
    delay(1);
    sendTimeout--;
  }
  

    /*---- Send data every 10min ----*/
  if(lastDataSent_s >= 600){
    #ifdef GAS_SENSOR
    gas_sensor_send_data();
    #endif

    #ifdef WATER_SENSOR
    water_sensor_send_data();
    #endif

    #ifdef DOOR_SENSOR
    door_sensor_send_data();
    #endif
  }
  //send data if there is any to send
  lastDataSent_s++;
}


/**
*	Checks how long the button is pressed:
*
*	-	>5s The sensor is reset
*	.
*	@param 	none
*	@return none
*/
void sensor_button_pressed(void){
    uint8_t count = 0;
    if(digitalRead(BUTTON_PRESS_PIN) == 0){
      while(digitalRead(BUTTON_PRESS_PIN) == 0){
        count++;
        delay(500);
        if(count >= 9){
          sensor_reset();
          break;
        }
      }
    }
}


/**
*	Resets the variables of sensor and base station ID in flash and restarts the microcontroller
*
*	@param 	none
*	@return none
*/
void sensor_reset(void){
  #ifdef DEBUG
    Serial.println("Sensor reset");
  #endif
  digitalWrite(Reset, LOW);
}

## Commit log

2022-11-09 Initial Pi Pico setup and SDK
2022-11-09 Removed Raspberry Pi Pico SDK
2022-11-09 RFM66W
    Added new Arduino ide project file
    Added RFM66W Datasheet
2022-11-09 Sensor Communication doc
2022-11-10 Raspi Pico Docs moved
2022-11-11 Sensor Reference Manual, added Program flow chart
2022-12-04 water sensor added
2022-12-04 led added
2022-12-04 gas sensor added & driver implemented
2022-12-04 sensor fritz file
    [BaseSensor.fzz]
2022-12-04 Sensor base functionality
    button works
    FreeRTOS events
    smoke detector modules work
2022-12-18 All hardware drivers working
2023-02-07 sensor firmware stm initial commit
2023-05-02 complete rfm integration
    [sensor_firmware Debug.cfg]
2023-06-03 adafruit project
    [BaseSensor.fzz, DoorSensor.fzz, SmokeSensor.fzz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]
2023-06-08 working firmware all sensors

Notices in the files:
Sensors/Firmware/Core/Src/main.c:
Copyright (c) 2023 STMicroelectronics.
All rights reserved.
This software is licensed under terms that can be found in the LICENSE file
